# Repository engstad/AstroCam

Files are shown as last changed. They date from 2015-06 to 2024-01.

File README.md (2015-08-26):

# AstroCam

My hobby project is to create a camera suitable for astronomy pictures. Here you can follow my work. It is slow going, since I don't have much time to allocate for this. So don't expect too many updates.

For now I have been focusing on three things:

1. understanding Analog Device's H-driver and ADC chip ADDI7013,
2. creating the power circuitry required for the many chips,
3. creating the PCB for the CCD camera chip.

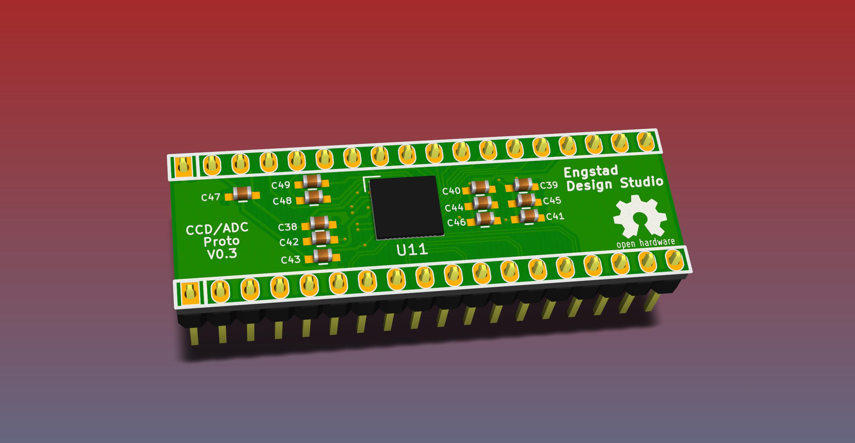
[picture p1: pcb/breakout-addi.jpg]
ADDI7013 breakout board


So far, only V0.2 of the ADDI breakout board has been produced and I'm in the process of testing it:

Pop board

And it works!

Measurements


So, that means that I'll start working on the camera parts next.

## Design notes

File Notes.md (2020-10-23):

# Xilinx

Check: https://www.xilinx.com/support/documentation/application_notes/xapp524-serial-lvds-adc-interface.pdf

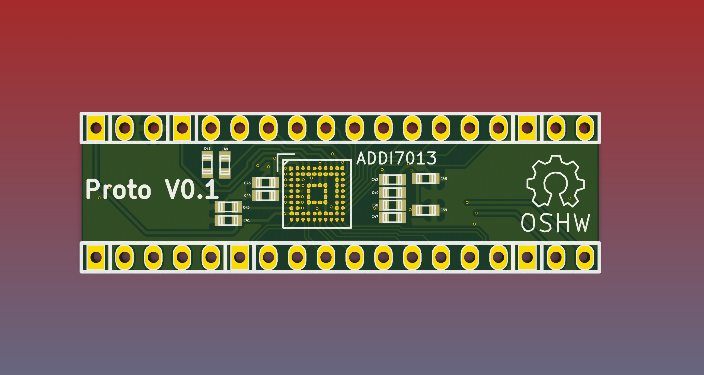
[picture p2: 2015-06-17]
pcb/AstroCam-Proto-Front.png

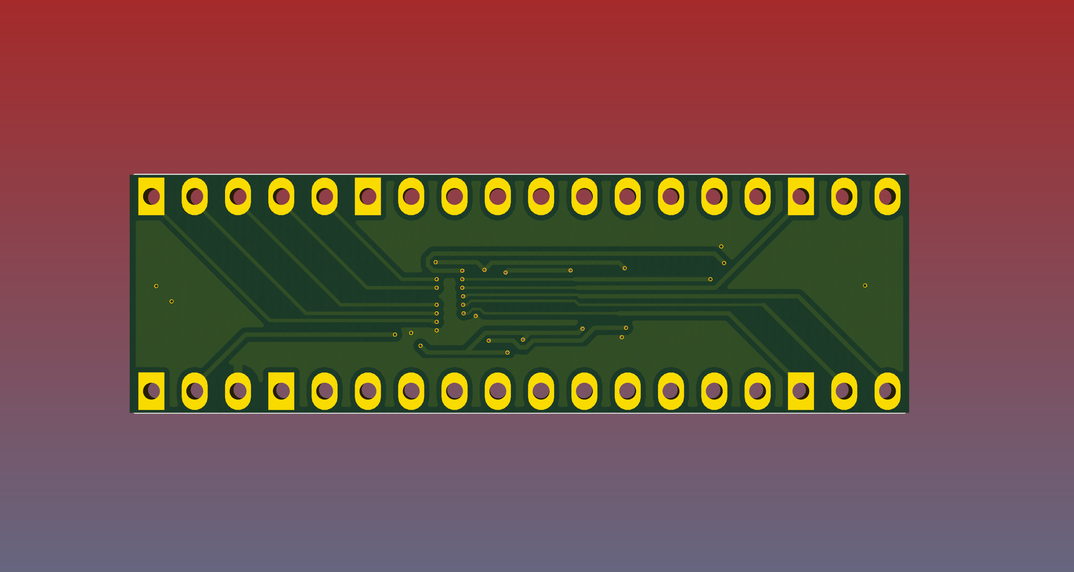
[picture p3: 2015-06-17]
pcb/AstroCam-Proto-Back.png

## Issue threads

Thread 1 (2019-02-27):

ADDI7013 programming

dn76, 2019-02-27:
Greetings, I couldn't find a better way to communicate with you. I bumped into this AstroCam project accidentally because I've been searching for information on ISTAG CCD drivers like ADDI7013 or ADDI7015, I'm trying to design astronomical CCD camera. While Analog Devices is ignoring my e-mail inquires on this matter, I was wondering if you could share some guidance on how to program them? Sorry for bugging you.

engstad, 2019-03-02:
Interesting, my hobby project has been to make my own astro camera. ;-)

Yeah, what I found was that the ADDI701x docs aren't very helpful and the
support nonexistent. The guy that drove the creation of those chips has
left the company, so there's also that.

How far are you on yours? I've gotten side-tracked quite a bit, so my
project is still on-hold.

PKE

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

dn76, 2019-03-07:
Hi, nice to meet you. My name is Denis. The camera I'm designing is at a
very early stage. I've got lucky to obtain a giant KAF-16803 sensor and
would like to build a camera as compact as possible, hence my interest in
Analog Devices AFE, it replaces a lot of discrete electronics. BTW, I've
designed and built a couple astronomical cameras before.

So, I had this question for you if you don't mind. What is the output file
of ISATG software and how you load it into AADI701x chip?

Cheers!
Denis Nikitin

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

engstad, 2019-03-07:
Nice to meet you!

As far as I remember (but I will check closer this weekend), the CCD
drivers are running sort of an assembly language, backed by a very simple
"CPU" (though state-machine, is probably a better term). This is what
drives the horizontal drivers. I tried to run their DOS tools to create
these assembly programs, but that didn't work for me. I also tried to
reverse-engineer the assembly format, but there were definitely bits in
there that I don't understand. Either way, what I came to conclude was that
I would only use the ADDI7013 for read-outs, not for running the
horizontal/vertical drivers. I'm already needing an FPGA in order to turn
the LVDS signals into storage, so the FPGA can just as well drive the
sensor. In terms of programming the chip, it seems to be a fairly standard
SPI interface to set internal registers. You just need to know the right
addresses to set, because there are many!

Maybe you could help me out too? I'm still not 100% clear on how the CCD
sensor works, especially with respect to the substrate, as well as the
timing. I'm working with a Sony IXD something CCD, and their documentation
of the horizontal/vertical timing is pretty horrible. What was the best
"general" description of driving the CCD sensors? Who can answer things
like, "if you want to take long exposure, how should you setup the
timings?", "if you want to take a short exposure, but many (say 10
frames-per-second), how do you set it up?".

I'm also quite out of the depth in terms of what I need for the read-outs.
Some designs are using two transistors, presumably to increase the current
(?), while Analog Devices seem to use a specialized chip for it (current
amplification?)

PKE

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

dn76, 2019-03-07:
Thank you for the information. I guess I will stick with the ADDI idea for
now and should I have no luck with it, I will definitely follow you path.

Yeah, I might be able to help, I understand CCDs pretty well. Could you
specify what kind of sensor you use. Should be ICX... something if it is
Sony, not IXD. They all are somewhat different so it's better to be more
specific. Interlaced sensors should have the most nasty timing diagrams. I
will tell you everything about substrate and clock signals ones you tell me
the exact component. In general you can't use ADDI7013 directly with a CCD,
that's because CCDs use strange voltage levels like 0V to -7V for vertical
clocks, so you need to use a voltage level converter in between, which also
should have an ability to drive high capacitance, that's because the CCD
inputs have tens of nano-farads of input capacitance.

In terms of readout, again it all depends on specific CCD component. But
normally any CCD has an open drain output amplifier stage, that kind of
output stage produces current which depends on the light intensity in
pixels. To convert that current into voltage that you measure with your ADC
you need to connect the output to a load. Sometimes the load is built in
the CCD sensor, like in some Sony chips, in that case the next stage will
be a emitter follower based on BJT transistors. If the load is external, it
can be just a resistor with emitter follower based on BJT transistors. Or
it can be an active constant current load, like the one from Analog
Devices. Active load has an advantage that it is more linear than the
resistive one and also allows for faster readout , however it is also more
noisy.

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

engstad, 2019-03-08:
Looked it up, it's a ICX825AQA, chip. 12V/-7V, with vertical drivers (VT1-4), and two sets of horizontal drivers (RG, LH1, H1S, H1T, H2S, H2T) and two outputs (it's split in left and right). The Sony data-sheet recommends to do something like this:

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

For driving the vertical lines (and the substrate control), I'm using a CXD3400N):

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

For the output, it's suggesting:

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

I'm not sure if I am supposed to additionally, or instead, use a ADA4800...

dn76, 2019-03-11:
I'm gonna try to find a more meaningful description of its timing diagram.
Bear with me.

I was able to find a schematics of a popular about 10 years ago Arthemis
CCD astrocamera. It's based on ICX285 which is a slightly older version  of
your ICX825

http://www.pmdo.com/artdownloads/UnpopulatedBoards.pdf

See page 39. The output of the CCD is connected to the gate of a FET, which
means the CCD output amplifier has built in load.

Also, I'm not sure if you're aware but Sony has discontinued most of its
CCD sensors, so I'd recommend you to switch to the ON semicanductor CCDs,
which is actually ex Kodak business.

Cheers

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

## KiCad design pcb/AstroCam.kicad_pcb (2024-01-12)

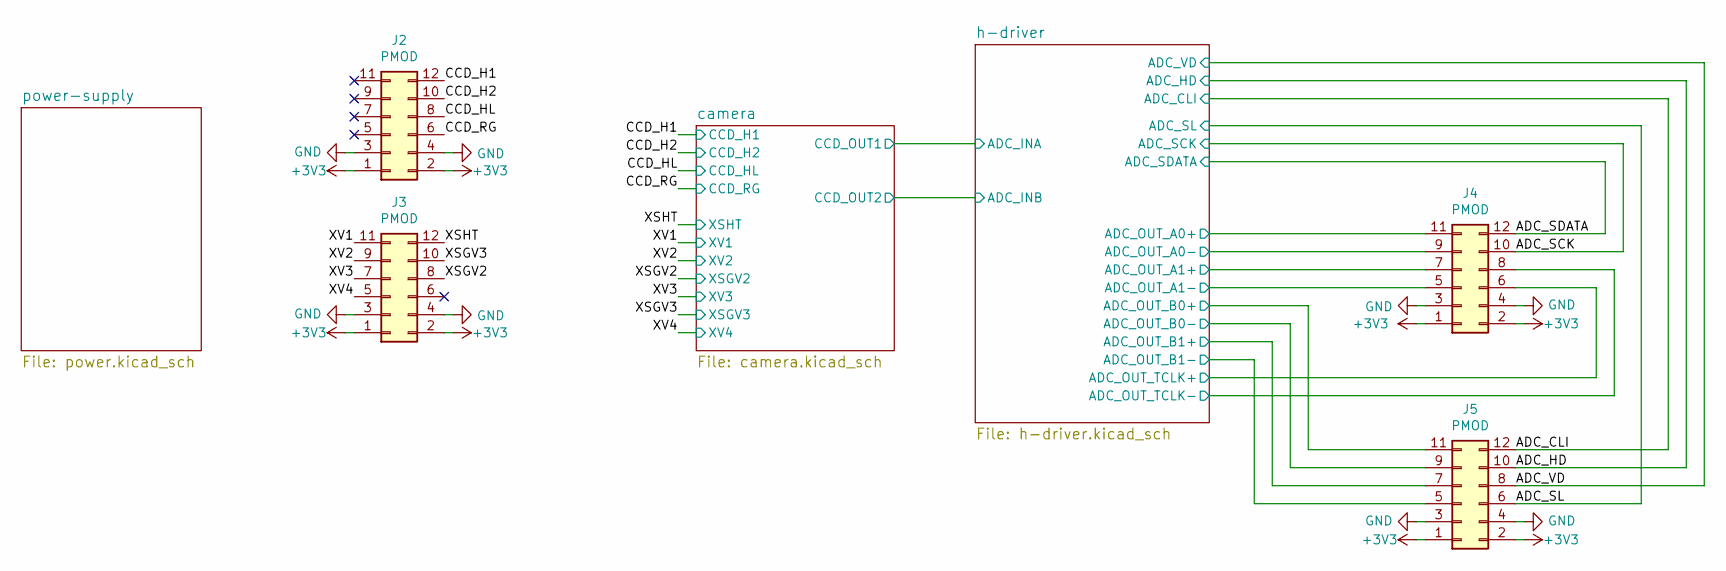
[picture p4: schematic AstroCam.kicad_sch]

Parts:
J2, J3, J4, J5: PMOD; PinHeader_2x06_P2.54mm_Horizontal

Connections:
+3V3: J2.1, J2.2, J3.1, J3.2, J4.1, J4.2, J5.1, J5.2; also elsewhere on the board
/ADC_CLI: J5.12; also elsewhere on the board
/ADC_HD: J5.10; also elsewhere on the board
/ADC_SCK: J4.10; also elsewhere on the board
/ADC_SDATA: J4.12; also elsewhere on the board
/ADC_SL: J5.6; also elsewhere on the board
/ADC_VD: J5.8; also elsewhere on the board
/CCD_H1: J2.12; also elsewhere on the board
/CCD_H2: J2.10; also elsewhere on the board
/CCD_HL: J2.8; also elsewhere on the board
/CCD_RG: J2.6; also elsewhere on the board
/XSGV2: J3.8; also elsewhere on the board
/XSGV3: J3.10; also elsewhere on the board
/XSHT: J3.12; also elsewhere on the board
/XV1: J3.11; also elsewhere on the board
/XV2: J3.9; also elsewhere on the board
/XV3: J3.7; also elsewhere on the board
/XV4: J3.5; also elsewhere on the board
/h-driver/ADC_OUT_A0+: J4.11; also elsewhere on the board
/h-driver/ADC_OUT_A0-: J4.9; also elsewhere on the board
/h-driver/ADC_OUT_A1+: J4.7; also elsewhere on the board
/h-driver/ADC_OUT_A1-: J4.5; also elsewhere on the board
/h-driver/ADC_OUT_B0+: J5.11; also elsewhere on the board
/h-driver/ADC_OUT_B0-: J5.9; also elsewhere on the board
/h-driver/ADC_OUT_B1+: J5.7; also elsewhere on the board
/h-driver/ADC_OUT_B1-: J5.5; also elsewhere on the board
/h-driver/ADC_OUT_TCLK+: J4.6; also elsewhere on the board
/h-driver/ADC_OUT_TCLK-: J4.8; also elsewhere on the board

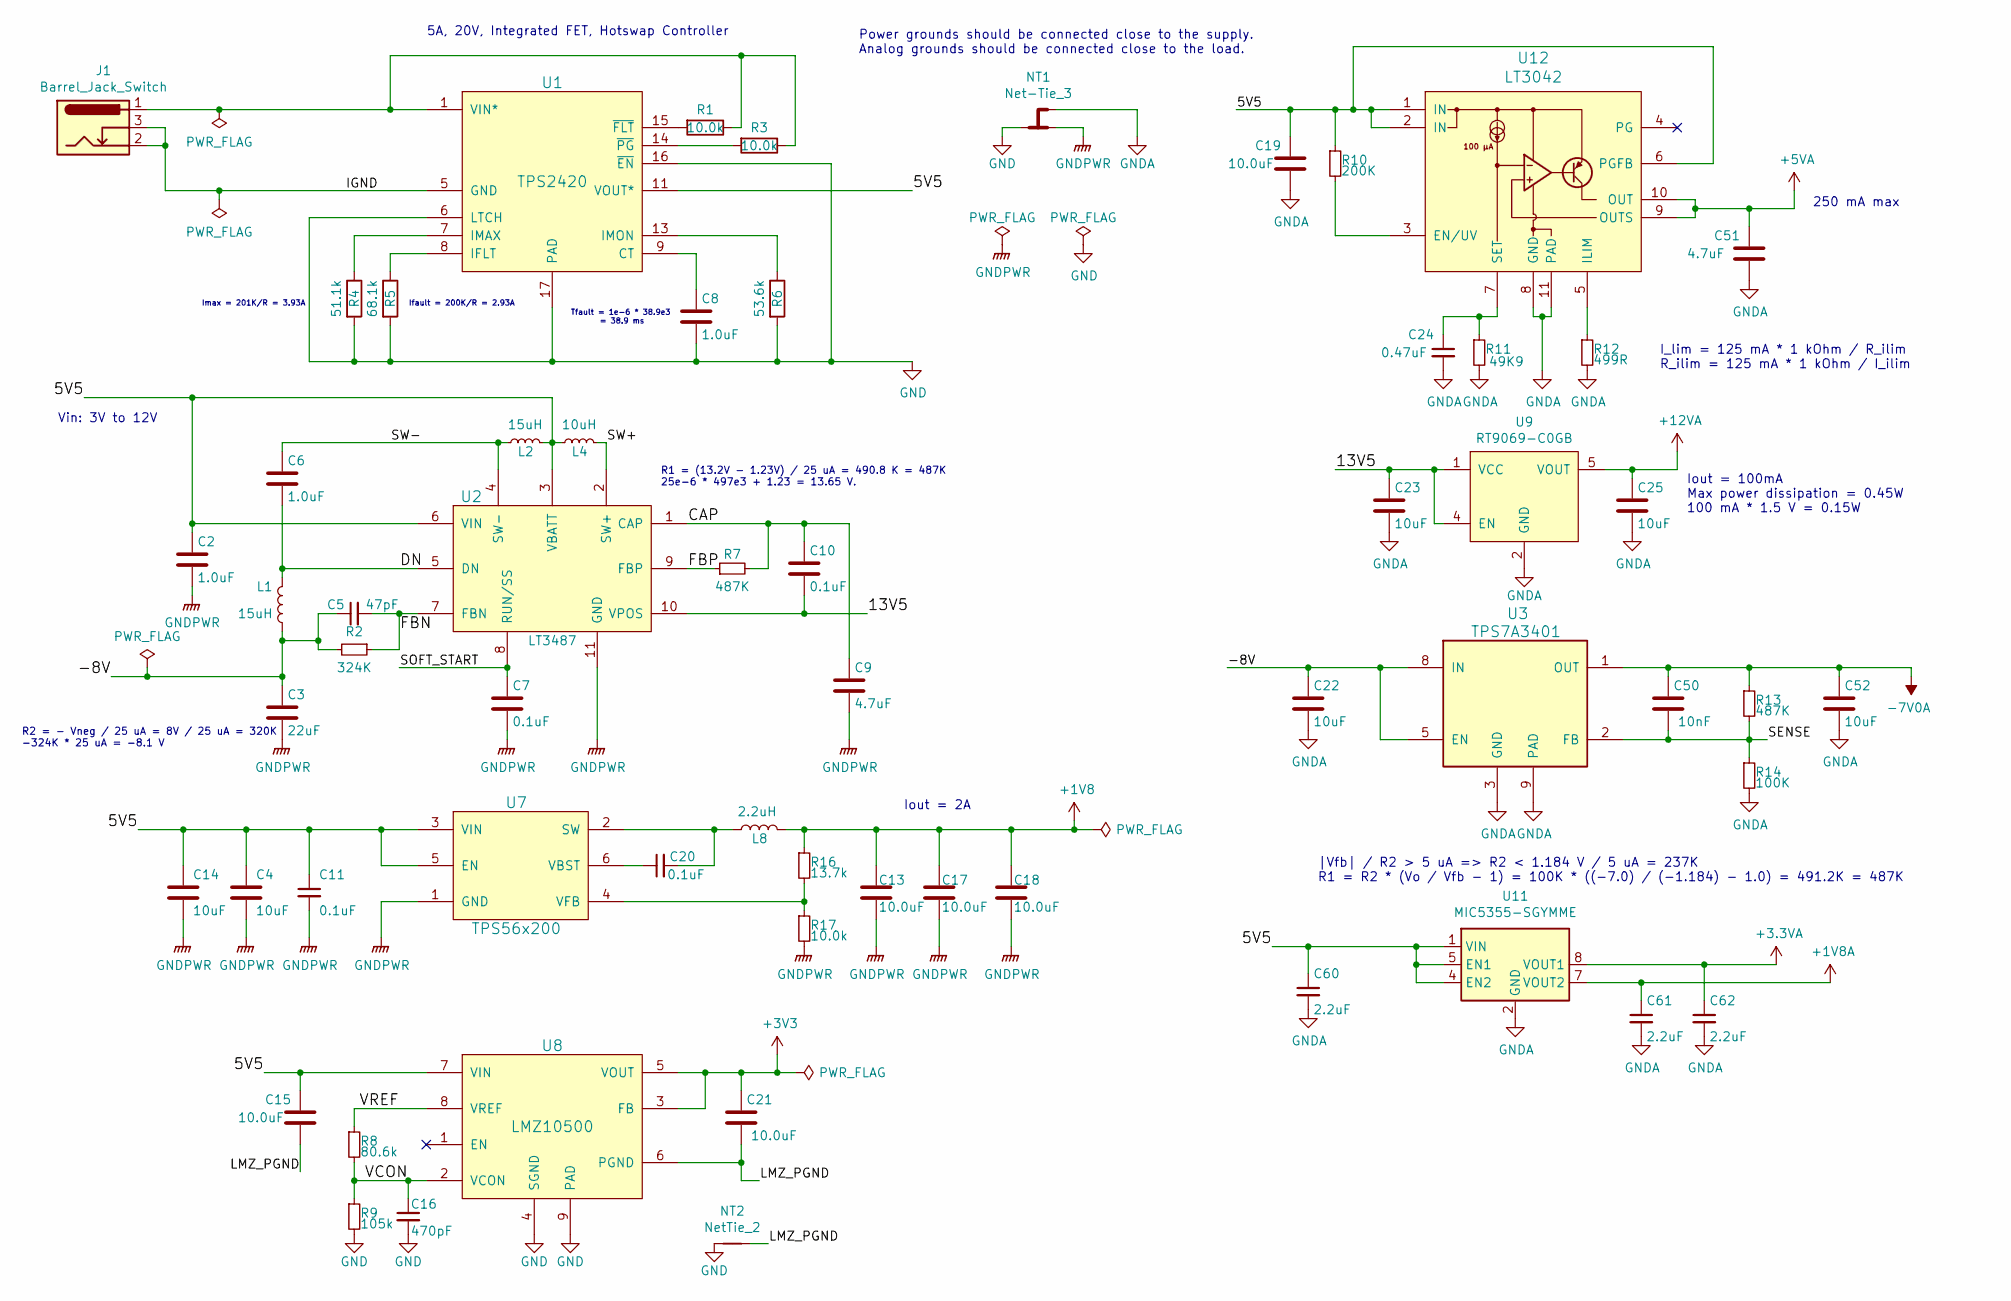
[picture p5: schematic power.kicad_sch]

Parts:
C2, C6, C8: 1.0uF; C_0603_1608Metric
C3: 22uF; C_1206_3216Metric
C4, C14: 10uF; C_0805_2012Metric
C5: 47pF; C_0603_1608Metric
C7, C10, C11, C20: 0.1uF; C_0603_1608Metric
C9, C51: 4.7uF; C_0805_2012Metric
C13, C17, C18, C19: 10.0uF; C_1206_3216Metric
C15, C21: 10.0uF; C_0805_2012Metric
C16: 470pF; C_0603_1608Metric
C22, C23, C25, C52: 10uF; C_1206_3216Metric
C24: 0.47uF; C_0603_1608Metric
C50: 10nF; C_0603_1608Metric
C60, C61, C62: 2.2uF; C_0603_1608Metric
J1: Barrel_Jack_Switch; BarrelJack_Wuerth_6941xx301002
L1, L2: 15uH; L_Wurth-4018
L4: 10uH; L_Wurth-4018
L8: 2.2uH; L_0805_2012Metric
NT1: Net-Tie_3; NetTie-3_SMD_Pad0.5mm
NT2: NetTie_2; NetTie-2_THT_Pad0.3mm
R1, R3, R17: 10.0k; R_0603_1608Metric
R2: 324K; R_0603_1608Metric
R4: 51.1k; R_0603_1608Metric
R5: 68.1k; R_0603_1608Metric
R6: 53.6k; R_0603_1608Metric
R7, R13: 487K; R_0603_1608Metric
R8: 80.6k; R_0603_1608Metric
R9: 105k; R_0603_1608Metric
R10: 200K; R_0603_1608Metric
R11: 49K9; R_0603_1608Metric
R12: 499R; R_0603_1608Metric
R14: 100K; R_0603_1608Metric
R16: 13.7k; R_0603_1608Metric
U1: TPS2420; QFN-16-1EP_4x4mm_P0.65mm_EP2.7x2.7mm_ThermalVias
U2: LT3487; DFN-10-1EP_3x3mm_P0.5mm_EP1.7x2.5mm
U3: TPS7A3401; VSSOP-8_3.0x3.0mm_P0.65mm
U7: TPS56x200; SOT-23-6
U8: LMZ10500; Texas_Instruments-LLP-8
U9: RT9069-C0GB; SOT-23-5
U11: MIC5355-SGYMME; MSOP-8-1EP_3x3mm_P0.65mm_EP2.5x3mm_Mask1.73x2.36mm_ThermalV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
U12: LT3042; DFN-10-1EP_3x3mm_P0.5mm_EP1.65x2.38mm_ThermalVias

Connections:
+1V8: C13.1, C17.1, C18.1, L8.2, R16.1; also elsewhere on the board
+1V8A: C61.1, U11.7 (VOUT2)
+3.3VA: C62.1, U11.8 (VOUT1); also elsewhere on the board
+3V3: C21.1, U8.3 (FB), U8.5 (VOUT); also elsewhere on the board
+5VA: C51.1, U12.9 (OUTS), U12.10 (OUT); also elsewhere on the board
+12VA: C25.1, U9.5 (VOUT); also elsewhere on the board
-7V0A: C50.1, C52.1, R13.1, U3.1 (OUT); also elsewhere on the board
/power-supply/5V5: C2.1, C4.1, C11.1, C14.1, C15.1, C19.1, C60.1, L2.2, L4.1, R10.1, U1.10 (VOUT*), U1.11 (VOUT*), U1.12 (VOUT*), U2.3 (VBATT), U2.6 (VIN), U7.3 (VIN), U7.5 (EN), U8.7 (VIN), U11.1 (VIN), U11.4 (EN2), U11.5 (EN1), U12.1 (IN), U12.2 (IN), U12.6 (PGFB)
/power-supply/13V5: C10.2, C23.1, U2.10 (VPOS), U9.1 (VCC), U9.4 (EN)
/power-supply/-8V: C3.1, C5.1, C22.1, L1.1, R2.2, U3.5 (EN), U3.8 (IN)
/power-supply/CAP: C9.1, C10.1, R7.2, U2.1 (CAP)
/power-supply/DN: C6.2, L1.2, U2.5 (DN)
/power-supply/FBN: C5.2, R2.1, U2.7 (FBN)
/power-supply/FBP: R7.1, U2.9 (FBP)
/power-supply/IGND: J1.2, J1.3, U1.5 (GND)
/power-supply/LMZ_PGND: C15.2, C21.2, NT2.2, U8.6 (PGND)
/power-supply/SENSE: C50.2, R13.2, R14.1, U3.2 (FB)
/power-supply/SOFT_START: C7.1, U2.8 (RUN/SS)
/power-supply/SW+: L4.2, U2.2 (SW+)
/power-supply/SW-: C6.1, L2.1, U2.4 (SW-)
/power-supply/VCON: C16.1, R8.2, R9.1, U8.2 (VCON)
/power-supply/VREF: R8.1, U8.8 (VREF)
GNDPWR: C2.2, C3.2, C4.2, C7.2, C9.2, C11.2, C13.2, C14.2, C17.2, C18.2, NT1.1, R17.2, U2.11 (GND), U7.1 (GND)
unnamed: C8.1, U1.9 (CT)
unnamed: R5.1, U1.8 (IFLT)
unnamed: R4.1, U1.7 (IMAX)
unnamed: R6.1, U1.13 (IMON)
unnamed: R1.2, U1.15 (~FLT)
unnamed: R3.2, U1.14 (~PG)
unnamed: C20.2, L8.1, U7.2 (SW)
unnamed: C20.1, U7.6 (VBST)
unnamed: R16.2, R17.1, U7.4 (VFB)
unnamed: R10.2, U12.3 (EN/UV)
unnamed: R12.1, U12.5 (ILIM)
unnamed: C24.1, R11.1, U12.7 (SET)
VIN*: J1.1, R1.1, R3.1, U1.1 (VIN*), U1.2 (VIN*), U1.3 (VIN*), U1.4 (VIN*)

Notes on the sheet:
R2 = - Vneg / 25 uA = 8V / 25 uA = 320K -324K * 25 uA = -8.1 V
Iout = 2A
I_lim = 125 mA * 1 kOhm / R_ilim R_ilim = 125 mA * 1 kOhm / I_ilim
Tfault = 1e-6 * 38.9e3 = 38.9 ms
250 mA max
Vin: 3V to 12V
Ifault = 200K/R = 2.93A
Imax = 201K/R = 3.93A
Power grounds should be connected close to the supply. Analog grounds should be connected close to the load.
R1 = (13.2V - 1.23V) / 25 uA = 490.8 K = 487K 25e-6 * 497e3 + 1.23 = 13.65 V.
|Vfb| / R2 > 5 uA => R2 < 1.184 V / 5 uA = 237K R1 = R2 * (Vo / Vfb - 1) = 100K * ((-7.0) / (-1.184) - 1.0) = 491.2K = 487K
Iout = 100mA Max power dissipation = 0.45W 100 mA * 1.5 V = 0.15W
5A, 20V, Integrated FET, Hotswap Controller

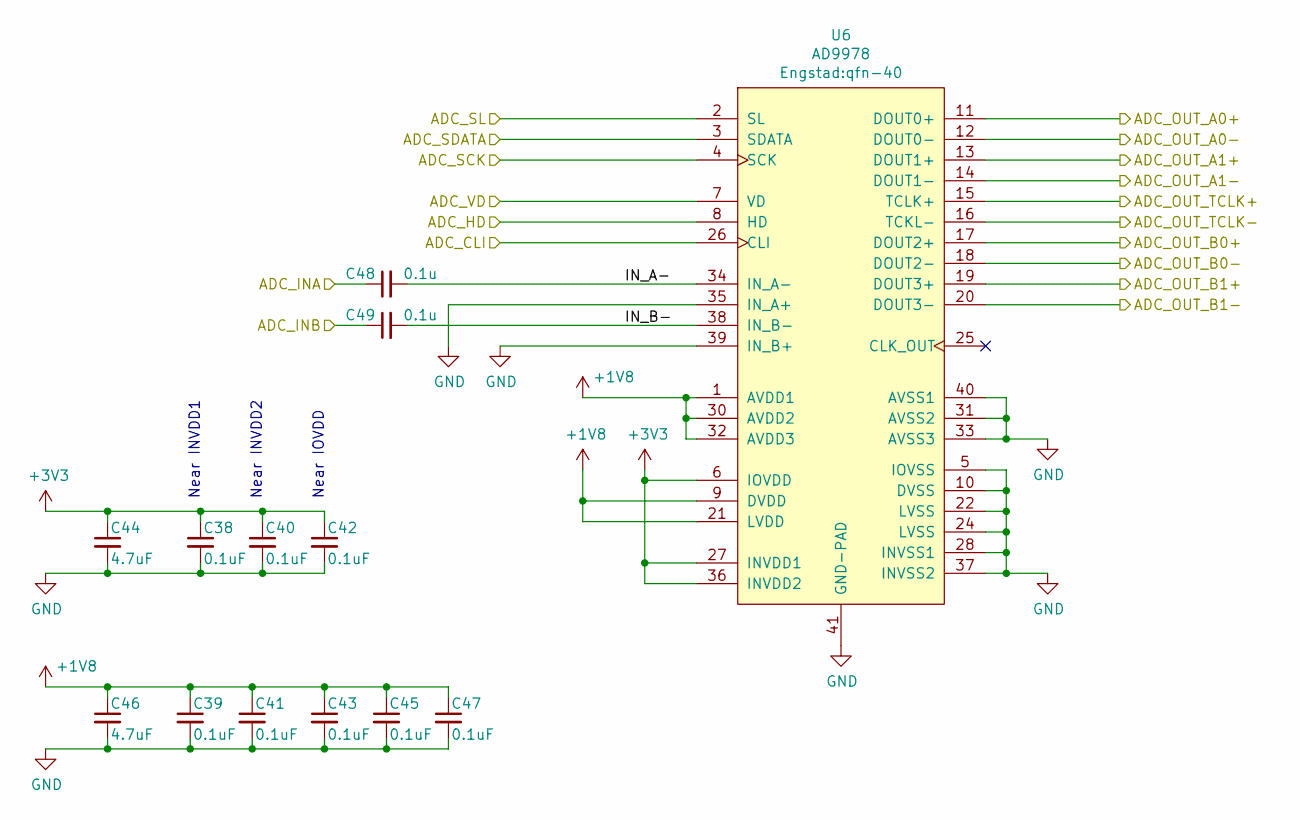
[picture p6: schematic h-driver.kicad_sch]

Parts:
C38, C39, C40, C41, C42, C43, C45, C47: 0.1uF; C_0603_1608Metric
C44, C46: 4.7uF; C_0805_2012Metric
C48, C49: 0.1u; C_0603_1608Metric
U6: AD9978; qfn-40

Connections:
+1V8: C39.1, C41.1, C43.1, C45.1, C46.1, C47.1, U6.1 (AVDD1), U6.9 (DVDD), U6.21 (LVDD), U6.30 (AVDD2), U6.32 (AVDD3); also elsewhere on the board
+3V3: C38.1, C40.1, C42.1, C44.1, U6.6 (IOVDD), U6.27 (INVDD1), U6.36 (INVDD2); also elsewhere on the board
/ADC_CLI: U6.26 (CLI); also elsewhere on the board
/ADC_HD: U6.8 (HD); also elsewhere on the board
/ADC_SCK: U6.4 (SCK); also elsewhere on the board
/ADC_SDATA: U6.3 (SDATA); also elsewhere on the board
/ADC_SL: U6.2 (SL); also elsewhere on the board
/ADC_VD: U6.7 (VD); also elsewhere on the board
/camera/CCD_OUT1: C48.1; also elsewhere on the board
/camera/CCD_OUT2: C49.1; also elsewhere on the board
/h-driver/ADC_OUT_A0+: U6.11 (DOUT0+); also elsewhere on the board
/h-driver/ADC_OUT_A0-: U6.12 (DOUT0-); also elsewhere on the board
/h-driver/ADC_OUT_A1+: U6.13 (DOUT1+); also elsewhere on the board
/h-driver/ADC_OUT_A1-: U6.14 (DOUT1-); also elsewhere on the board
/h-driver/ADC_OUT_B0+: U6.17 (DOUT2+); also elsewhere on the board
/h-driver/ADC_OUT_B0-: U6.18 (DOUT2-); also elsewhere on the board
/h-driver/ADC_OUT_B1+: U6.19 (DOUT3+); also elsewhere on the board
/h-driver/ADC_OUT_B1-: U6.20 (DOUT3-); also elsewhere on the board
/h-driver/ADC_OUT_TCLK+: U6.15 (TCLK+); also elsewhere on the board
/h-driver/ADC_OUT_TCLK-: U6.16 (TCKL-); also elsewhere on the board
/h-driver/IN_A-: C48.2, U6.34 (IN_A-)
/h-driver/IN_B-: C49.2, U6.38 (IN_B-)

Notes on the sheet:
Near IOVDD
Near INVDD1
Near INVDD2

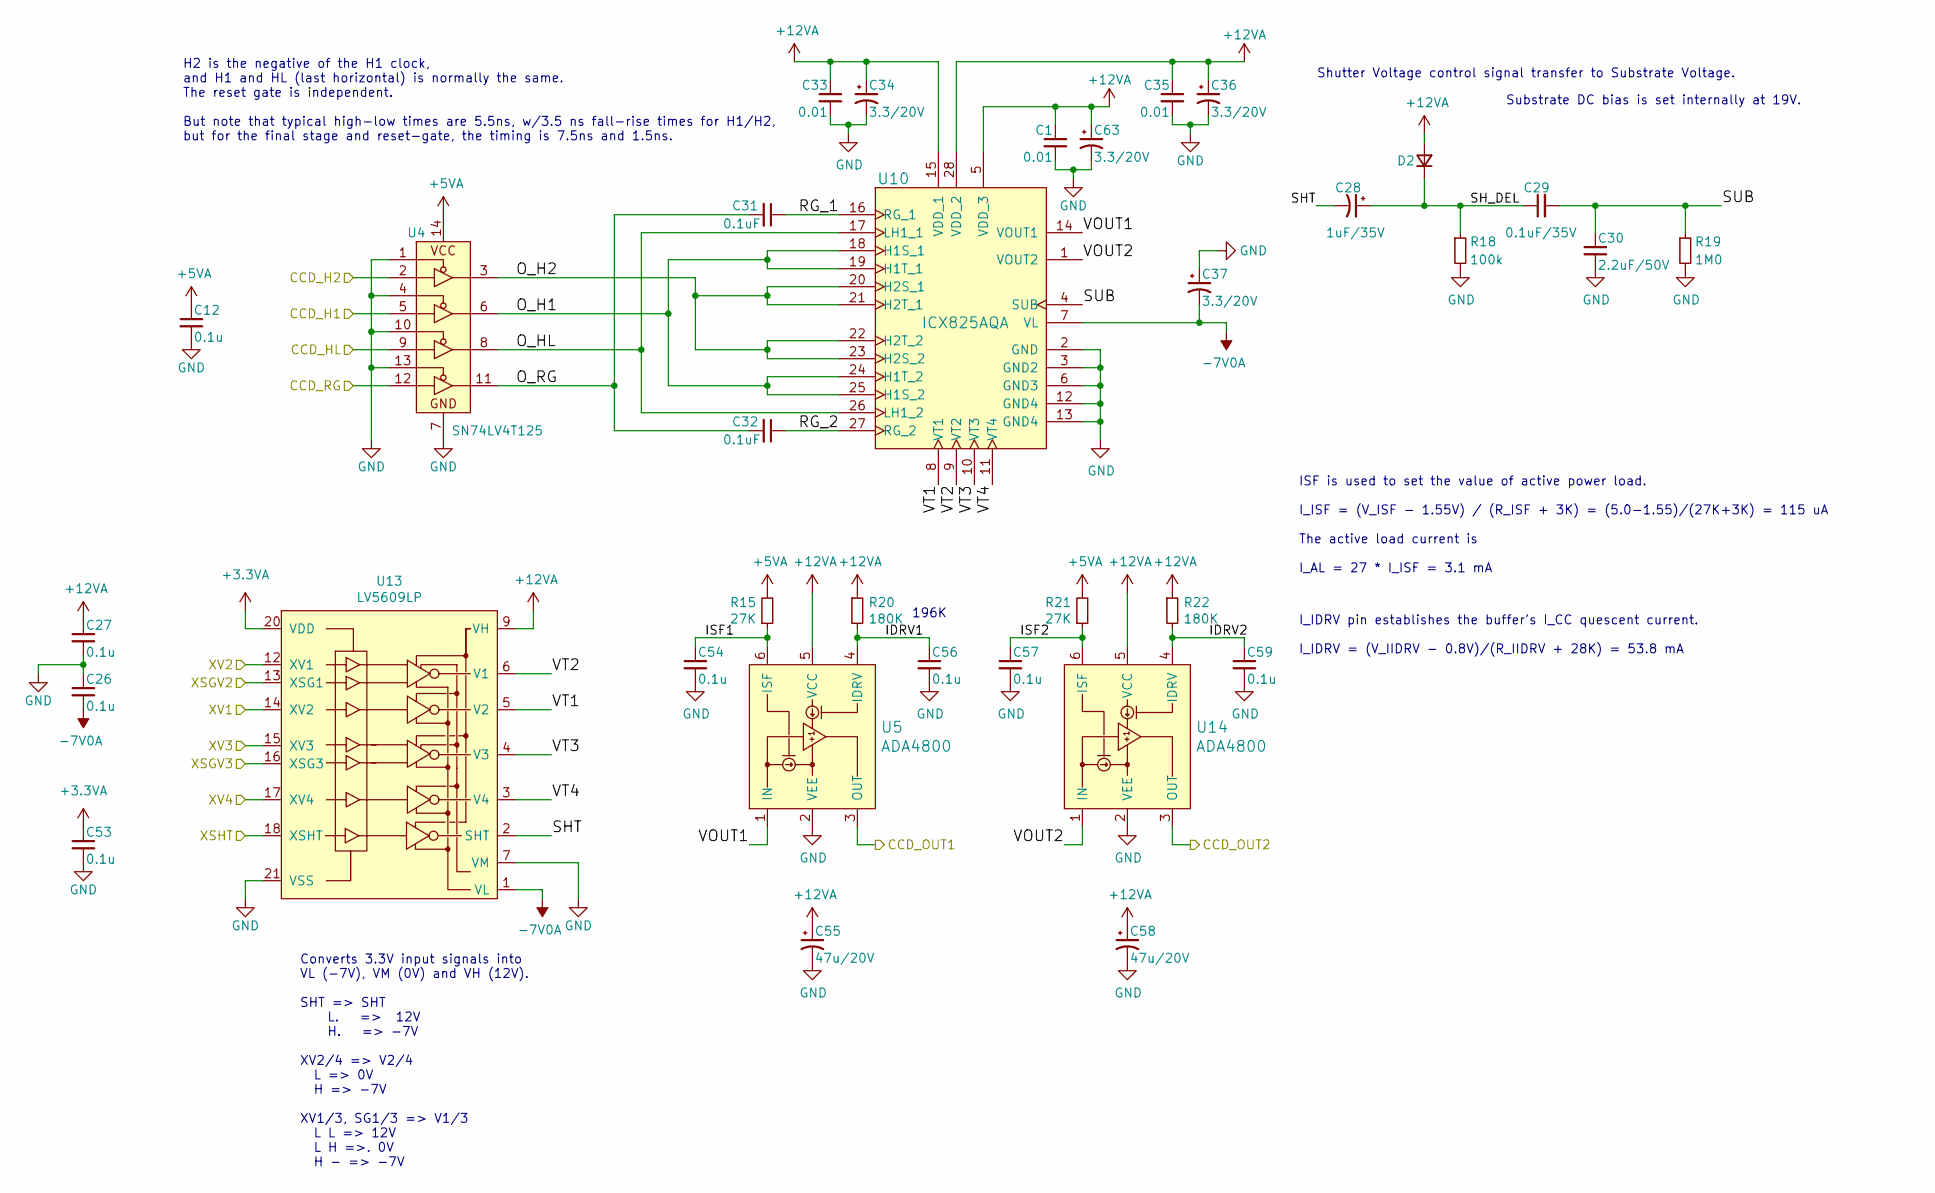
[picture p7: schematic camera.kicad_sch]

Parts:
C1, C33, C35: 0.01; C_0603_1608Metric
C12, C26, C27, C53, C54, C56, C57, C59: 0.1u; C_0603_1608Metric
C28: 1uF/35V; CP_EIA-1608-08_AVX-J
C29: 0.1uF/35V; C_0805_2012Metric
C30: 2.2uF/50V; C_0805_2012Metric
C31, C32: 0.1uF; C_0603_1608Metric
C34: 3.3/20V; CP_EIA-3528-12_Kemet-T
C36, C37, C63: 3.3/20V; CP_EIA-1608-08_AVX-J
C55, C58: 47u/20V; C_1206_3216Metric
D2: D; D_SOD-123
R15, R21: 27K; R_0603_1608Metric
R18: 100k; R_0603_1608Metric
R19: 1M0; R_0603_1608Metric
R20, R22: 180K; R_0603_1608Metric
U4: SN74LV4T125; Texas_R-PDSO-G14
U5, U14: ADA4800; lfcsp-cp-6-4
U10: ICX825AQA; ICX825
U13: LV5609LP; ON_Semiconductor-VCT24-3.5x3.5mm

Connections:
+3.3VA: C53.1, U13.20 (VDD); also elsewhere on the board
+5VA: C12.1, R15.2, R21.2, U4.14 (VCC); also elsewhere on the board
+12VA: C1.1, C27.1, C33.1, C34.1, C35.1, C36.1, C55.1, C58.1, C63.1, D2.2 (A), R20.1, R22.1, U5.5 (VCC), U10.5 (VDD_3), U10.15 (VDD_1), U10.28 (VDD_2), U13.9 (VH), U14.5 (VCC); also elsewhere on the board
-7V0A: C26.2, C37.2, U10.7 (VL), U13.1 (VL); also elsewhere on the board
/CCD_H1: U4.5 (2A); also elsewhere on the board
/CCD_H2: U4.2 (1A); also elsewhere on the board
/CCD_HL: U4.9 (3A); also elsewhere on the board
/CCD_RG: U4.12 (4A); also elsewhere on the board
/XSGV2: U13.13 (XSG1); also elsewhere on the board
/XSGV3: U13.16 (XSG3); also elsewhere on the board
/XSHT: U13.18 (XSHT); also elsewhere on the board
/XV1: U13.14 (XV2); also elsewhere on the board
/XV2: U13.12 (XV1); also elsewhere on the board
/XV3: U13.15 (XV3); also elsewhere on the board
/XV4: U13.17 (XV4); also elsewhere on the board
/camera/CCD_OUT1: U5.3 (OUT); also elsewhere on the board
/camera/CCD_OUT2: U14.3 (OUT); also elsewhere on the board
/camera/IDRV1: C56.1, R20.2, U5.4 (IDRV)
/camera/IDRV2: C59.1, R22.2, U14.4 (IDRV)
/camera/ISF1: C54.1, R15.1, U5.6 (ISF)
/camera/ISF2: C57.1, R21.1, U14.6 (ISF)
/camera/O_H1: U4.6 (2Y), U10.18 (H1S_1), U10.19 (H1T_1), U10.24 (H1T_2), U10.25 (H1S_2)
/camera/O_H2: U4.3 (1Y), U10.20 (H2S_1), U10.21 (H2T_1), U10.22 (H2T_2), U10.23 (H2S_2)
/camera/O_HL: U4.8 (3Y), U10.17 (LH1_1), U10.26 (LH1_2)
/camera/O_RG: C31.2, C32.2, U4.11 (4Y)
/camera/RG_1: C31.1, U10.16 (RG_1)
/camera/RG_2: C32.1, U10.27 (RG_2)
/camera/SHT: C28.2, U13.2 (SHT)
/camera/SH_DEL: C28.1, C29.1, D2.1 (K), R18.1
/camera/SUB: C29.2, C30.1, R19.1, U10.4 (SUB)
/camera/VOUT1: U5.1 (IN), U10.14 (VOUT1)
/camera/VOUT2: U10.1 (VOUT2), U14.1 (IN)
/camera/VT1: U10.8 (VT1), U13.5 (V2)
/camera/VT2: U10.9 (VT2), U13.6 (V1)
/camera/VT3: U10.10 (VT3), U13.4 (V3)
/camera/VT4: U10.11 (VT4), U13.3 (V4)

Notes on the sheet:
196K
Shutter Voltage control signal transfer to Substrate Voltage.
Substrate DC bias is set internally at 19V.
ISF is used to set the value of active power load. I_ISF = (V_ISF - 1.55V) / (R_ISF + 3K) = (5.0-1.55)/(27K+3K) = 115 uA The active load current is I_AL = 27 * I_ISF = 3.1 mA
H2 is the negative of the H1 clock, and H1 and HL (last horizontal) is normally the same. The reset gate is independent. But note that typical high-low times are 5.5ns, w/3.5 ns fall-rise times for H1/H2, but for the final stage and reset-gate, the timing is 7.5ns and 1.5ns.
I_IDRV pin establishes the buffer's I_CC quescent current. I_IDRV = (V_IIDRV - 0.8V)/(R_IIDRV + 28K) = 53.8 mA
Converts 3.3V input signals into VL (-7V), VM (0V) and VH (12V). SHT => SHT L. => 12V H. => -7V XV2/4 => V2/4 L => 0V H => -7V XV1/3, SG1/3 => V1/3 L L => 12V L H =>. 0V H - => -7V

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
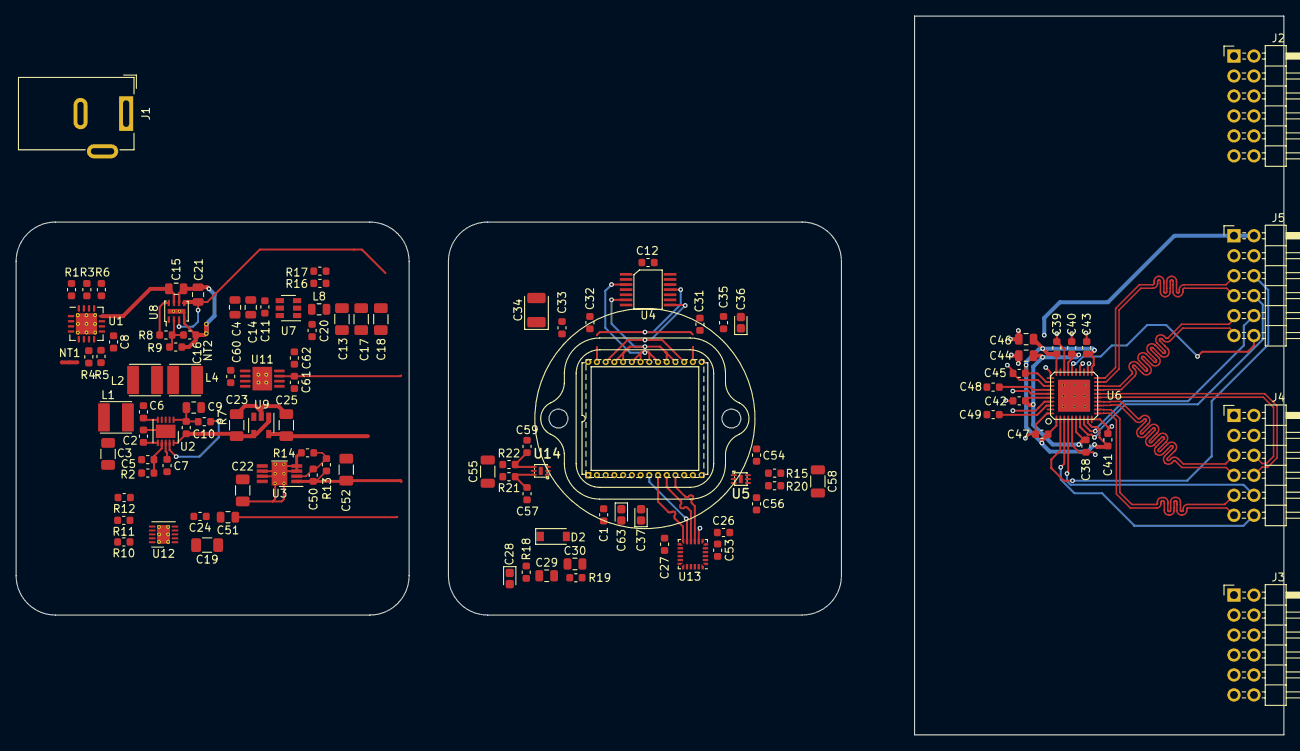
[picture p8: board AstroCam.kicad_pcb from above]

Board: 2 copper layers, 161.3 x 91.4 mm, 111 parts (0 on the bottom side), 87 nets.

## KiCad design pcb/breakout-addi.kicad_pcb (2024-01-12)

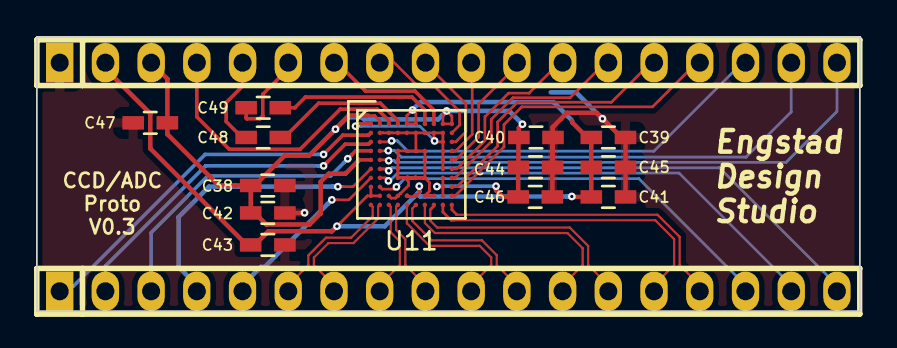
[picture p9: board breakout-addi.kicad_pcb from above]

Board: 2 copper layers, 45.7 x 15.2 mm, 15 parts (0 on the bottom side), 38 nets.

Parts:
C38, C39, C40, C41, C42, C43, C44, C45, C46: 0.1uF; C_0603_HandSoldering
C47: 4.7uF; C_0603_HandSoldering
C48, C49: 0.1u; C_0603_HandSoldering
P2, P3: CONN_01X18; pin_strip_18
U11: ADDI7013; csp-bga-bc-76-3

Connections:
/h-driver/1V8: C39.1, C41.1, C43.1, C45.1, P3.2, U11.A5, U11.A6, U11.H1, U11.J1, U11.J2, U11.J5, U11.J6
/h-driver/3V3: C38.1, C40.1, C42.1, C44.1, C46.1, C47.1, P3.3, U11.A2, U11.A9, U11.A10, U11.E1, U11.G9, U11.H9, U11.J9
/h-driver/A0+: P2.6, U11.K1
/h-driver/A0-: P2.7, U11.K2
/h-driver/A1+: P2.8, U11.K3
/h-driver/A1-: P2.9, U11.K4
/h-driver/B0+: P2.12, U11.K7
/h-driver/B0-: P2.13, U11.K8
/h-driver/B1+: P2.14, U11.K9
/h-driver/B1-: P2.15, U11.K10
/h-driver/CLI: P2.1, U11.B1
/h-driver/GP01: P2.2, U11.C1
/h-driver/GP02: P2.3, U11.D1
/h-driver/GP03: P2.4, U11.F1
/h-driver/GP04: P2.5, U11.G1
/h-driver/H1: P3.13, U11.G10
/h-driver/H2: P3.12, U11.F10
/h-driver/H3: P3.11, U11.E10
/h-driver/H4: P3.10, U11.D10
/h-driver/HD: P2.17, U11.G2
/h-driver/HL1: P3.14, U11.H10
/h-driver/HL2: P3.9, U11.C10
/h-driver/IN_A+: C48.1, P3.5
/h-driver/IN_A-: P3.4, U11.A3
/h-driver/IN_B+: C49.1, P3.6
/h-driver/IN_B-: P3.7, U11.A8
/h-driver/RG1: P3.15, U11.J10
/h-driver/RG2: P3.8, U11.B10
/h-driver/SCK: P3.17, U11.D2
/h-driver/SDATA: P3.18, U11.E2
/h-driver/SL: P3.16, U11.C2
/h-driver/SYNC: P2.18, U11.F2
/h-driver/TCLK+: P2.10, U11.K5
/h-driver/TCLK-: P2.11, U11.K6
/h-driver/VD: P2.16, U11.H2
GND: C38.2, C39.2, C40.2, C41.2, C42.2, C43.2, C44.2, C45.2, C46.2, C47.2, P3.1, U11.A1, U11.B2, U11.B3, U11.B4, U11.B5, U11.B6, U11.B7, U11.B8, U11.B9, U11.C9, U11.D4, U11.D5, U11.D6, U11.D7, U11.D9, U11.E4, U11.E7, U11.E9, U11.F4, U11.F7, U11.F9, U11.G4, U11.G5, U11.G6, U11.G7, U11.J3, U11.J4, U11.J7, U11.J8
unnamed: C48.2, U11.A4
unnamed: C49.2, U11.A7

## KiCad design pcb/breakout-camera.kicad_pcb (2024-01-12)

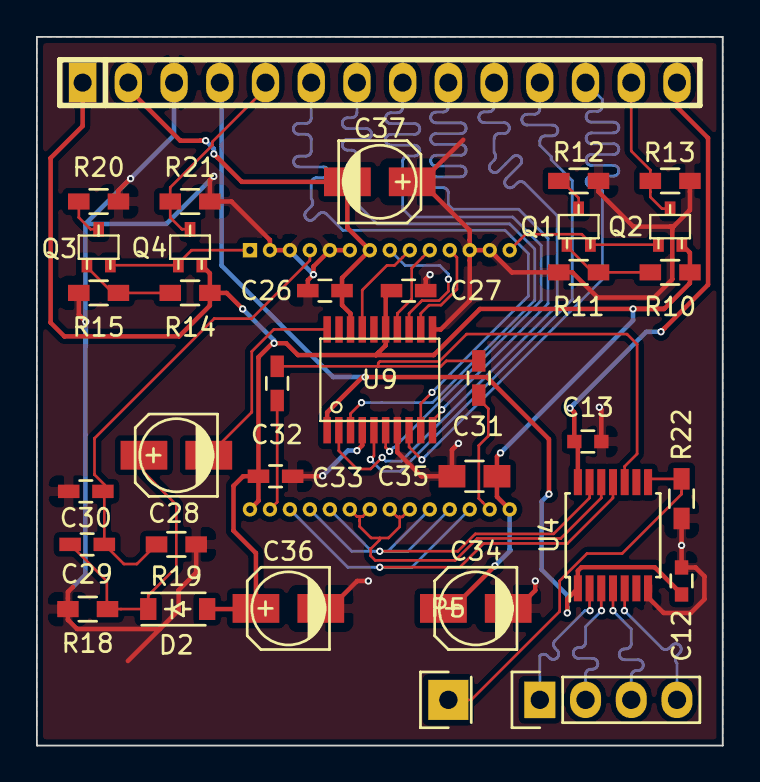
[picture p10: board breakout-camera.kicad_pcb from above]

Board: 2 copper layers, 38.1 x 39.4 mm, 36 parts (1 on the bottom side), 38 nets.

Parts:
C12, C13: 0.1u; C_0603
C26, C27: 0.1u; C_0603_HandSoldering
C28: 1u/35V; c_elec_4x5.3
C29: 0.1uF; C_0603_HandSoldering
C30: 2200pF; C_0603_HandSoldering
C31, C32: 0.1; C_0603_HandSoldering
C33: 0.01; C_0603_HandSoldering
C34, C36, C37: 3.3/20V; c_elec_4x5.3
C35: 0.01; C_0805_HandSoldering
D2: D; SOD-123
P4: CONN_01X04; Socket_Strip_Straight_1x04
P5: CONN_01X01; Socket_Strip_Straight_1x01
P10: CONN_01X14; pin_strip_14
Q1, Q3: 2SC5095; sot323
Q2, Q4: MT3S20TU; sot323
R10, R11, R14, R15: 10K; R_0603_HandSoldering
R12, R20: 1.17K; R_0603_HandSoldering
R13, R21: 1.74K; R_0603_HandSoldering
R18: 100k; R_0603_HandSoldering
R19: 1M0; R_0603_HandSoldering
R22: 10.0k; R_0603_HandSoldering
U4: TXB0104; TSSOP-14_4.4x5mm_Pitch0.65mm
U9: CXD3400N; tssop-20
U10: ICX825AQA; ICX825

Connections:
/camera/3V3: C12.1, P10.4, U4.1, U9.1
/camera/5V0: C13.1, P10.14, U4.14
/camera/12V: C27.1, C33.2, C34.1, C35.2, C36.1, D2.2, P10.1, Q2.3, Q4.3, R10.1, R14.1, U9.15, U10.15, U10.28
/camera/-7V: C26.1, C37.2, P10.2, U9.18, U10.7
/camera/B1: Q1.1, R10.2, R11.1
/camera/B2: Q3.1, R14.2, R15.1
/camera/CCD_OUT1: P10.13, Q2.2, R13.1
/camera/CCD_OUT2: P10.5, Q4.2, R21.1
/camera/E1: Q1.2, R12.1
/camera/E2: Q3.2, R20.1
/camera/ENH: P5.1, R22.1, U4.8
/camera/H1: P4.1, U4.2
/camera/H1S_1: U4.13, U10.18, U10.19, U10.24, U10.25
/camera/H2: P4.2, U4.3
/camera/H2S_1: U4.12, U10.20, U10.21, U10.22, U10.23
/camera/HL: P4.3, U4.4
/camera/LH1_1: U4.11, U10.17, U10.26
/camera/ORG: C31.2, C32.2, U4.10
/camera/RG: P4.4, U4.5
/camera/RG_1: C31.1, U10.16
/camera/RG_2: C32.1, U10.27
/camera/SUB: C29.2, C30.1, R19.1, U10.4
/camera/VOUT1: Q1.3, Q2.1, U10.14
/camera/VOUT2: Q3.3, Q4.1, U10.1
/camera/VT1: U9.13, U10.8
/camera/VT2: U9.17, U10.9
/camera/VT3: U9.14, U10.10
/camera/VT4: U9.12, U10.11
/camera/XSGV2: P10.11, U9.5
/camera/XSGV3: P10.12, U9.8
/camera/XSHT: P10.10, U9.2
/camera/XV1: P10.6, U9.9
/camera/XV2: P10.7, U9.3
/camera/XV3: P10.8, U9.6
/camera/XV4: P10.9, U9.10
GND: C12.2, C13.2, C26.2, C27.2, C30.2, C33.1, C34.2, C35.1, C36.2, C37.1, P10.3, R11.2, R12.2, R13.2, R15.2, R18.2, R19.2, R20.2, R21.2, R22.2, U4.7, U9.4, U9.7, U9.11, U10.2, U10.3, U10.5, U10.6, U10.12, U10.13
unnamed: C28.1, C29.1, D2.1, R18.1
unnamed: C28.2, U9.20

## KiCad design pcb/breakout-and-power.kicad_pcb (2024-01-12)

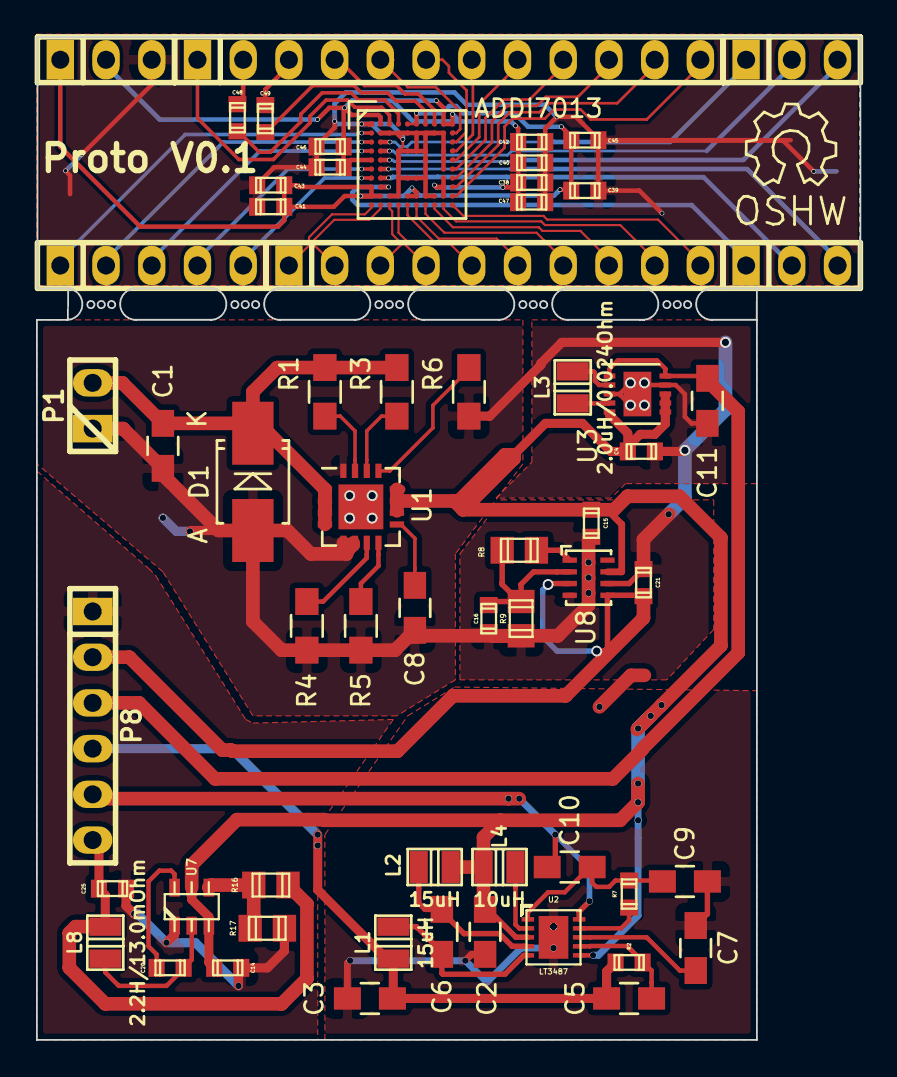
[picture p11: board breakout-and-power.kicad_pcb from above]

Board: 2 copper layers, 45.8 x 55.7 mm, 60 parts (0 on the bottom side), 66 nets.

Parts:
C1, C2, C6: 1.0uF; C_0805_HandSoldering
C3, C5: 47pF; C_0805_HandSoldering
C4: 2.20uF/2.80Mohm; c_0603
C7: 100nF; C_0805_HandSoldering
C8: 1.0F/11mOhm; C_0805_HandSoldering
C9: 4.7uF; C_0805_HandSoldering
C10: 0.1uF; C_0805_HandSoldering
C11: 10uF; C_0805_HandSoldering
C14: 10.0F/3.0mOhm; c_0603
C15: 10.0F/9Mohm; c_0603
C16: 470pF; c_0603
C20: 100nF; c_0603
C21: 10.0uF/9.0Mohm; c_0603
C25: 47F/3Mohm; c_0603
C38, C39, C40, C41, C42, C43, C44, C45, C46: 0.1uF; c_0603
C47: 4.7uF; c_0603
C48, C49: 0.1u; c_0603
D1: 9V/5W; Diode-SMB_Handsoldering
L1, L2: 15uH; inductor_smd_0805
L3: 2.0uH/0.024Ohm; inductor_smd_0805
L4: 10uH; inductor_smd_0805
L8: 2.2H/13.0mOhm; inductor_smd_0805
P1: CONN_01X02; pin_strip_2
P2: CONN_01X05; pin_strip_5
P3: CONN_01X10; pin_strip_10
P4, P6, P7: CONN_01X03; pin_strip_3
P5: CONN_01X12; pin_strip_12
P8: CONN_01X06; pin_socket_6
R1, R3: 10.0k; R_0805_HandSoldering
R2, R7: 324k; r_0603
R4: 51.1k; R_0805_HandSoldering
R5: 68.1k; R_0805_HandSoldering
R6: 53.6k; R_0805_HandSoldering
R8: 80.6k; r_0805
R9: 105k; r_0805
R16: 13.7k; r_0805
R17: 10.0k; r_0805
U1: TPS2420; QFN-16-1EP_4x4mm_Pitch0.65mm
U2: LT3487; dfn10-3x3
U3: TPS63002; DFN-10-1EP_3x3mm_Pitch0.5mm
U7: TPS56x200; sot23-6
U8: LMZ10500; llp-8
U11: ADDI7013; csp-bga-bc-76-3

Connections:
/h-driver/1V8: C39.1, C41.1, C43.1, C45.1, P7.1, U11.A5, U11.A6, U11.H1, U11.J1, U11.J2, U11.J5, U11.J6
/h-driver/3V3: C38.1, C40.1, C42.1, C44.1, C46.1, C47.1, P7.2, U11.A2, U11.A9, U11.A10, U11.E1, U11.G9, U11.H9, U11.J9
/h-driver/A0+: P3.1, U11.K1
/h-driver/A0-: P3.2, U11.K2
/h-driver/A1+: P3.3, U11.K3
/h-driver/A1-: P3.4, U11.K4
/h-driver/B0+: P3.7, U11.K7
/h-driver/B0-: P3.8, U11.K8
/h-driver/B1+: P3.9, U11.K9
/h-driver/B1-: P3.10, U11.K10
/h-driver/CLI: P2.1, U11.B1
/h-driver/GND: C38.2, C39.2, C40.2, C41.2, C42.2, C43.2, C44.2, C45.2, C46.2, C47.2, P7.3, U11.A1, U11.B2, U11.B3, U11.B4, U11.B5, U11.B6, U11.B7, U11.B8, U11.B9, U11.C9, U11.D4, U11.D5, U11.D6, U11.D7, U11.D9, U11.E4, U11.E7, U11.E9, U11.F4, U11.F7, U11.F9, U11.G4, U11.G5, U11.G6, U11.G7, U11.J3, U11.J4, U11.J7, U11.J8
/h-driver/GP01: P2.2, U11.C1
/h-driver/GP02: P2.3, U11.D1
/h-driver/GP03: P2.4, U11.F1
/h-driver/GP04: P2.5, U11.G1
/h-driver/H1: P5.10, U11.G10
/h-driver/H2: P5.9, U11.F10
/h-driver/H3: P5.8, U11.E10
/h-driver/H4: P5.7, U11.D10
/h-driver/HD: P6.2, U11.G2
/h-driver/HL1: P5.11, U11.H10
/h-driver/HL2: P5.6, U11.C10
/h-driver/IN_A+: C48.1, P5.2
/h-driver/IN_A-: P5.1, U11.A3
/h-driver/IN_B+: C49.1, P5.3
/h-driver/IN_B-: P5.4, U11.A8
/h-driver/RG1: P5.12, U11.J10
/h-driver/RG2: P5.5, U11.B10
/h-driver/SCK: P4.2, U11.D2
/h-driver/SDATA: P4.3, U11.E2
/h-driver/SL: P4.1, U11.C2
/h-driver/SYNC: P6.3, U11.F2
/h-driver/TCLK+: P3.5, U11.K5
/h-driver/TCLK-: P3.6, U11.K6
/h-driver/VD: P6.1, U11.H2
/power-supply/1V8: C25.1, L8.2, P8.6, R16.1
/power-supply/3V3: C21.1, P8.2, U8.3, U8.5
/power-supply/5V0: C11.1, P8.3, U3.1, U3.10
/power-supply/5V5: C2.1, C4.1, C14.1, C15.1, L2.2, L4.1, U1.10, U1.11, U1.12, U2.3, U2.6, U3.5, U3.6, U3.7, U3.8, U7.3, U7.5, U8.7
/power-supply/+12V: C10.2, P8.5, U2.10
/power-supply/-7V: C3.1, C5.1, L1.1, P8.4, R2.2
/power-supply/CAP: C9.1, C10.1, R7.2, U2.1
/power-supply/DN: C6.2, L1.2, U2.5
/power-supply/FBN: C5.2, R2.1, U2.7
/power-supply/FBP: R7.1, U2.9
/power-supply/GND: C1.2, C2.2, C3.2, C4.2, C7.2, C8.2, C9.2, C11.2, C14.2, C15.2, C16.2, C21.2, C25.2, D1.2, P8.1, R4.2, R5.2, R6.2, R9.2, R17.2, U1.5, U1.6, U1.16, U2.11, U3.3, U3.9, U3.11, U7.1, U8.4, U8.6, U8.9
/power-supply/V_BAT: C1.1, D1.1, R1.1, R3.1, U1.1, U1.2, U1.3, U1.4
unnamed: C6.1, L2.1, U2.4
unnamed: C7.1, U2.8
unnamed: C8.1, U1.9
unnamed: C16.1, R8.2, R9.1, U8.2
unnamed: C20.1, U7.6
unnamed: C20.2, L8.1, U7.2
unnamed: C48.2, U11.A4
unnamed: C49.2, U11.A7
unnamed: L3.1, U3.4
unnamed: L3.2, U3.2
unnamed: L4.2, U2.2
unnamed: R1.2, U1.15
unnamed: R3.2, U1.14
unnamed: R4.1, U1.7
unnamed: R5.1, U1.8
unnamed: R6.1, U1.13
unnamed: R8.1, U8.1
unnamed: R16.2, R17.1, U7.4

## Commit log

2015-06-12 re-arrange directory layout
    [AstroCam.kicad_pcb, AstroCam.sch, camera.sch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]
2015-06-12 initial experimentation with size constraints
    [AstroCam.kicad_pcb, AstroCam.sch, camera.sch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]
2015-06-15 More work on schematic
    [AstroCam.kicad_pcb, AstroCam.sch, camera.sch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]
2015-06-17 Work on proto breakout.
    [AstroCam.kicad_pcb, AstroCam.sch, camera.sch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]
2015-06-21 Lot's of back and forward with vendor.
    [AstroCam.kicad_pcb, Save.sch, breakout-addi.kicad_pcb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]
2015-07-03 more work
    [AstroCam.sch, breakout-addi.kicad_pcb, breakout-camera.kicad_pcb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]
2015-08-14 lots of work
    [AstroCam.kicad_pcb, AstroCam.sch, Save.sch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]
2015-08-14 Move into pcb folder
    [AstroCam.kicad_pcb, AstroCam.sch, Save.sch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]
2015-08-19 Confirm to Advanced Circuits
    [breakout-addi.kicad_pcb]
2015-08-20 more stuff
    [breakout-addi.kicad_pcb]
2020-10-23 Safety checkin.
    [AstroCam-2020-09-10-12-30-52.sch, AstroCam.kicad_pcb, AstroCam.sch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]
2020-10-31 A little more work.
    [AstroCam.kicad_pcb, AstroCam.sch, camera.sch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]
2021-06-15 Work on power system and horizontal driver.
    [AstroCam.kicad_pcb, AstroCam.sch, h-driver.sch]
2024-01-12 Start up work to revive this project.
    [AstroCam.kicad_pcb, AstroCam.kicad_sch, breakout-addi.kicad_pcb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]
